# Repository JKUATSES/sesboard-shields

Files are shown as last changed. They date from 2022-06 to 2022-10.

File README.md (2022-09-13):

## Contribution Instructions
---

1. Fork the code sesboard shields repository provided.

2. Make a topic branch. In your github, keep the master branch clean. Pull all changes, make sure your repository is up to date.
```shell
cd [repo-name] e.g. cd research-docs
git pull origin main
```

3. Create a new branch as follows
```shell
git checkout -b <your_branch_name> main
```

4. See all branches created
```shell
$ git branch main <your_name>
```

5. Push the new branch to github
```shell
$ git push origin -u <your_branch_name>
```

6. Make changes to the fork provided.

7. Check the status of the repo
```shell
git status
```
8. Add your changed files
```shell
git add .
```
9. Commit your changes
```shell
git commit -m "Commit message"
```
10. Push your code changes
```shell
git push --set-upstream origin <your_name>
```
8. Make a [pull request](https://www.digitalocean.com/community/tutorials/how-to-create-a-pull-request-on-github) to the [Repo Name]

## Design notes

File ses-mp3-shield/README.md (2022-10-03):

# SesBoard MP3 Shield

---
### Technical specifications

* Plug and Play for SesBoard V1.0  
* Interface
  * Serial UART Interface 
  * 7 Control buttons
* Directly drive 32 Ohm headset
* Onboard audio amplifier capable of driving 3W/4Ohm external loudspeaker
* 20 levels adjustable volume
* supports FAT16/FAT32 file systems
* Support both SD/SD-HC and UDisk
* Onboard 64Mbit flash memory for storage
* Supports copying audio files from SD card or U-disk to SPI flash
* Sleep mode
* Audio files supported
  * 16K~320kbps MP3 files
  * 8K~44.1 kHz Sample rates
  * (SPI FLASH supports only MP3 Files)
* Power supply : 4.5 - 5V
* State indicators
    * Green LED for indicating power on. Remains on as long as power is supplied
    * Blue LED for indicating when music is playing. Flashes at 1 sec interval when playing file and 0.5 sec when copying files
* Comes with Ses-mp3 library for configuration and usage with SESBoard V1.0

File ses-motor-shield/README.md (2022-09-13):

# SES-Board Motor Shield

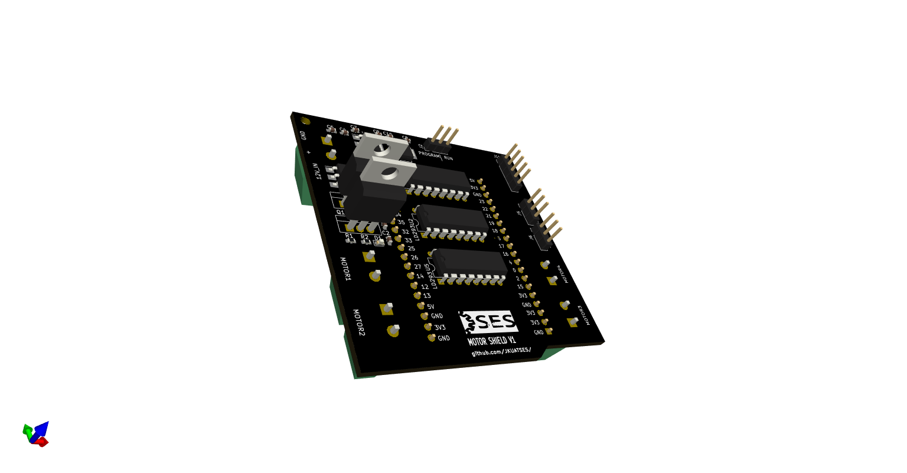
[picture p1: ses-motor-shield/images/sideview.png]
Sideview

---
The SES-Board Motor Shield features several outputs that can be useful to 
run motors for your projects needs. It features the following:
1. 2 servo motor control outputs
2. 4 DC motor control outputs
3. 1 stepper motor control output
4. External power supply
5. GPIO pins extension allowance
6. 3 LD293 Motor Driver ICs for high-current motor control
7. NEMA 17 stepper motor control 

The GPIO pins can be uses to connect to other sensors or outputs
you might want to control

# SES-Board Motor Shield Pin Assignments
The following table describes the pin assignment for each component
of the SES-Board motor shield:

| COMPONENT | PIN ON SESBOARD|
|---|---|
|**DC Motor 1**
|IN1|34|
|IN2|35|
|IN3|32|
|IN4|33|
|ENA|25|
|ENB|26|
|**DC Motor 2**| 
IN5|23|
|IN6|22|
|IN7|21|
|IN8|19|
|ENC|18|
|END|5|
|**Servo 1**
|SIG|17|
|Servo 2|
| SIG|16|
|**Stepper Motor**|
|A+|12|
|A-|13|
|B+|14|
|B-|15|

*** For ESP32, pins 34-39 cannot support PWM***

## Design 
### 1. Power supply
Power is derived from 12VDC supply. Because majority of motors run within this range,
this 12V is used to supply the motors with power. A 2-terminal block is used
to receive this 12V input. It then passes through a rectifier diode connected in forward bias 
to prevent reverse polarity damage. The diode drops 0.7V forward voltage.  
An LM317 voltage regulator is placed on the line for regulation. R1=240R and R2=2K. R1 and R2 ensure we get an output
of 12V regulated. Vout is given by this formula:
```c
Vout = 1.25(1 + R2/R1)
```
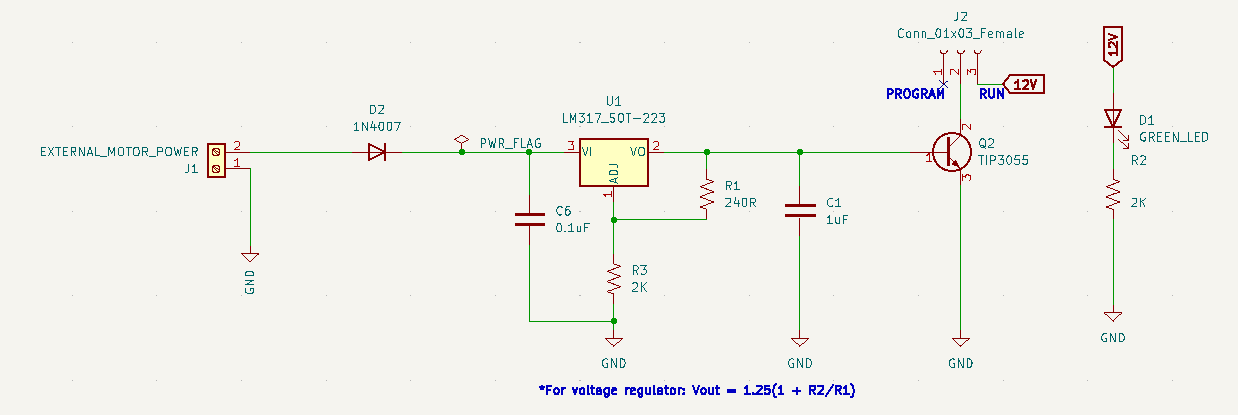
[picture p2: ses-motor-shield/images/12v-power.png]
12V

An NPN transistor (TIP3055), is connected to allow the shield to handle large current values when running.
A jumper is then placed at the collector of the transistor to allow for programming of the sesboard when using 
this motor shield.

****Make sure you cross-check your motor voltage range before using 12VDC***

<br>
Most servo motors operate under 6V of power. Fo us to supply this amount of voltage, we need to step down the 12V down to ~6V. We use an AMS1117-5V LDO regulator 
to provide us with ~5V which is enough for servo motors.   

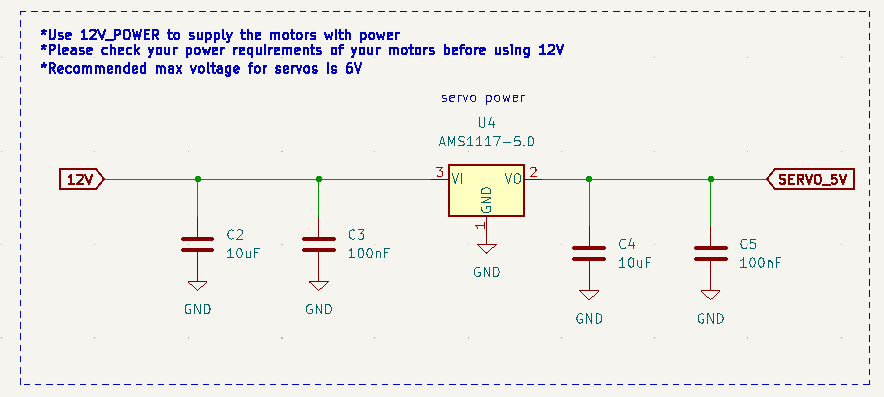
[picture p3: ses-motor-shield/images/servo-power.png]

<br>

During programming, we need to power the sesboard. We use AMS1117-3V3 LDO regulator for this task. It will provide
3V3 to the sesboard for optimal function.
There is a green LED to provide indication that there is power flowing in the circuit.

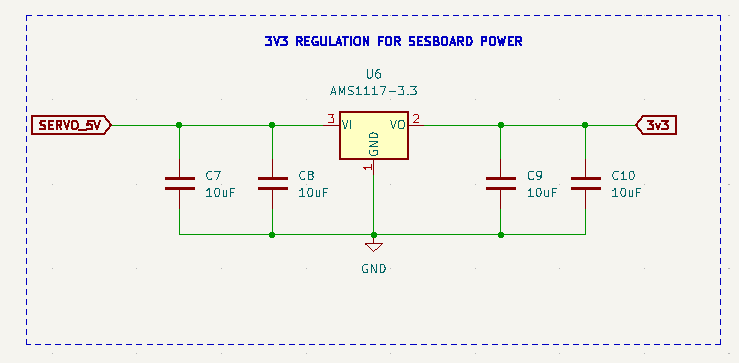
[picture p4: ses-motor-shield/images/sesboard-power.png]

<hr>  

### 2. Driver ICs
We use the very common L293D motor driver ICs. The L293D motor driver can drive up to 

## Screenshots
### Top
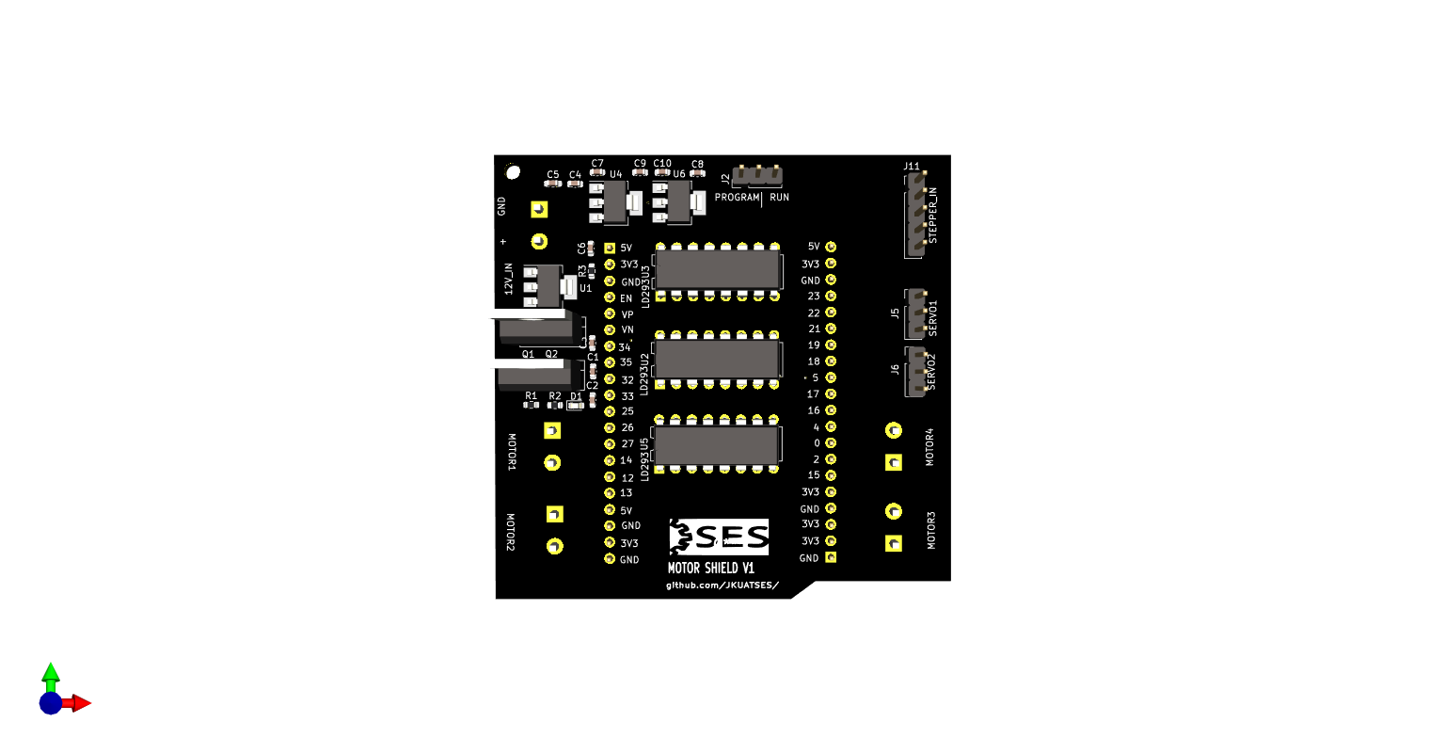
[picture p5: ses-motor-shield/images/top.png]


### Bottom
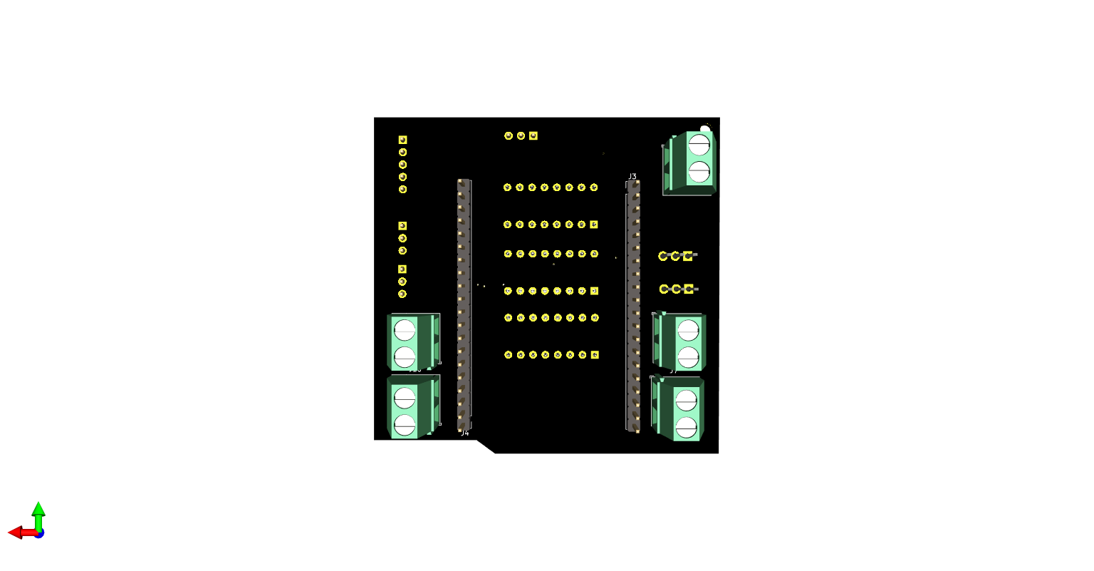
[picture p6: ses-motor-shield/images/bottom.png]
Bottom


### Left
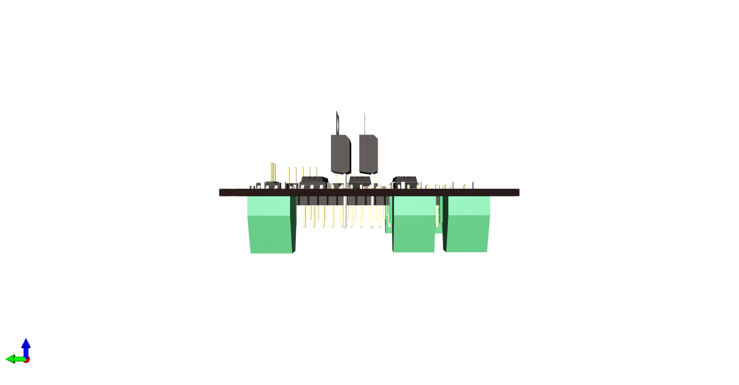
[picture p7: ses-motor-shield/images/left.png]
Left


# References
1. [https://lastminuteengineers.com/l293d-dc-motor-arduino-tutorial/](https://lastminuteengineers.com/l293d-dc-motor-arduino-tutorial/)
2. [https://lastminuteengineers.com/stepper-motor-l293d-arduino-tutorial/](https://lastminuteengineers.com/stepper-motor-l293d-arduino-tutorial/)
3. [https://randomnerdtutorials.com/esp32-pinout-reference-gpios/#:~:text=The%20ESP32%20LED%20PWM%20controller,can't%20generate%20PWM)] (https://randomnerdtutorials.com/esp32-pinout-reference-gpios/#:~:text=The%20ESP32%20LED%20PWM%20controller,can't%20generate%20PWM)

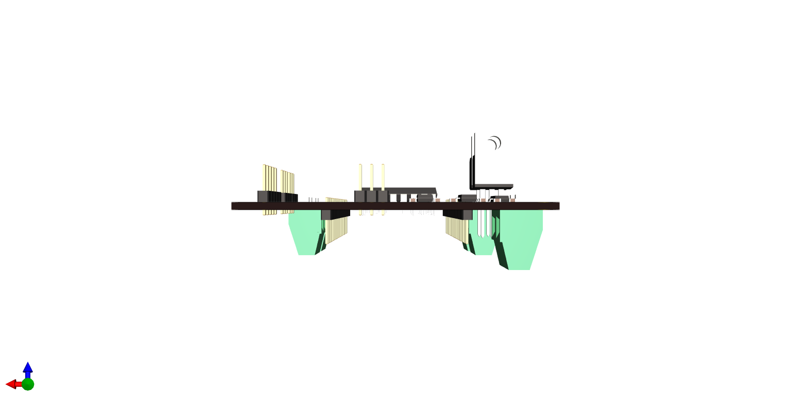
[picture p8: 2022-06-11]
ses-motor-shield/images/back.png

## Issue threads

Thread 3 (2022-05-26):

Check form factor for SES board for proper pin alignment

bytecod3, 2022-05-26:

bytecod3, 2022-06-01:
- [ ] Create a footprint for the sesboard pins in Kicad
- [ ]  Measure the form factor for the vertical allowance of the board's components

bytecod3, 2022-06-11:
The form factor was measured and confirmed. However, creating a footprint for the same is not logical because we need to place some components within the courtyard of the SESBOARD.
So we use header pads spaced similar to the form factor of the SESBOARD

Closed 2022-06-11.

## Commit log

2022-05-26 added power supply for motor shield
    [dc_driver_ics.kicad_sch, external_power.kicad_sch, motor-schematic.kicad_pcb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]
2022-05-30 added servo power supply
    [dc_driver_ics.kicad_sch, external_power.kicad_sch, motor-schematic.kicad_sch]
2022-06-01 added pin assignments
    [dc_driver_ics.kicad_sch, motor-schematic.kicad_sch]
2022-06-01 performed ERC
    [dc_driver_ics.kicad_sch, external_power.kicad_sch, motor-schematic.kicad_sch]
2022-06-03 added global labels for motor drivers
    [connectors.kicad_sch, dc_driver_ics.kicad_sch, external_power.kicad_sch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]
2022-06-03 added stepper connector
    [connectors.kicad_sch, dc_driver_ics.kicad_sch, motor-schematic.kicad_sch]
2022-06-03 added power toggle
    [connectors.kicad_sch, dc_driver_ics.kicad_sch, external_power.kicad_sch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]
2022-06-11 added view image
    [external_power.kicad_sch, motor-schematic.kicad_pcb]
2022-09-12 created: motor functions
2022-09-12 folder restructure
    [connectors.kicad_sch, dc_driver_ics.kicad_sch, external_power.kicad_sch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]
2022-09-13 finished board
    [connectors.kicad_sch, dc_driver_ics.kicad_sch, motor-schematic.kicad_pcb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]
2022-09-15 created function overloading for servo
    [external_power.kicad_sch, motor-schematic.kicad_sch]
2022-09-15 added servo sweep
2022-10-03 added: stepper motor examples
2022-10-03 created technical specs for ses-mp3 shield
    [dc_driver_ics.kicad_sch, external_power.kicad_sch]
2022-10-03 added specifications
    [mp3-schematics.kicad_pcb, mp3-schematics.kicad_sch]
